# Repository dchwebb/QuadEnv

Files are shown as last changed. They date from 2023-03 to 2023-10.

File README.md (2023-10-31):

# QuadEnv/L4O

Overview
--------
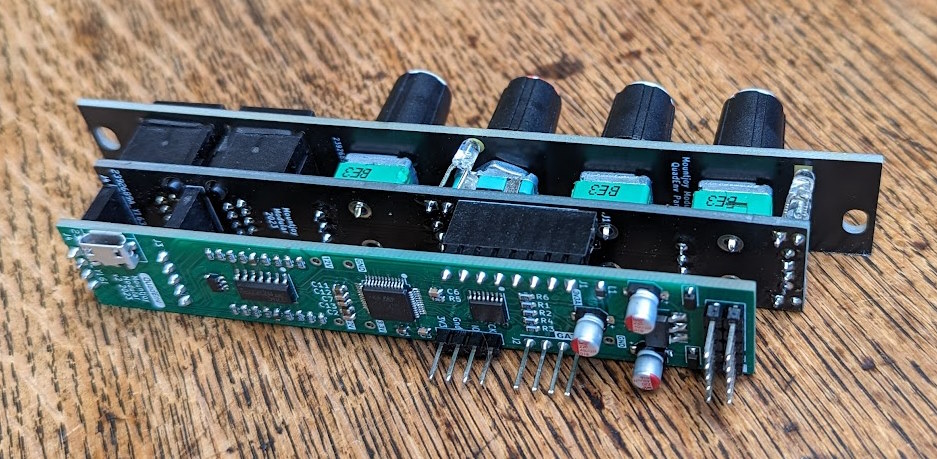
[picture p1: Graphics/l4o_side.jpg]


QuadEnv is a four-voice polyphonic ADSR envelope generator designed for use with the Eurorack Modular Synthesiser architecture. L4O is a four-voice sine wave LFO and uses the same hardware as QuadEnv.

Different front panels are provided for each mode, while the firmware, component and controls boards are dual mode.

As part of a range of compatilble Mountjoy Modular modules, polyphonic interconnections are made using RJ-45 cables (as used for Ethernet).

A USB serial console is provided for customising the envelope times and fade-in rates of the LFOs.

The third potentiometer (Sustain or Fade-In) has a momentary button which allows switching between the envelope and LFO modes via a long press.

QuadEnv
-------
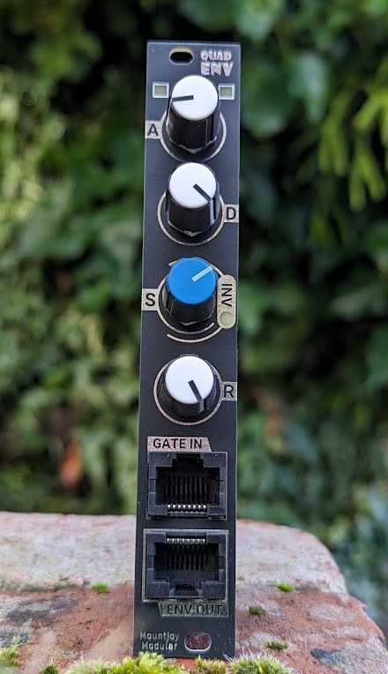
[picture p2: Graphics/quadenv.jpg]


The digital envelopes are modelled on a Roland System 100 system, with logarithmic/exponential attack/decay and release sections. The level of each envelope is displayed in a bank of LEDs at the top of the module.

A short press on the Sustain potentiometer button inverts the envelopes.

The USB serial console allows the envelope times to be scaled up or down for longer or shorter envelopes.

L4O
---
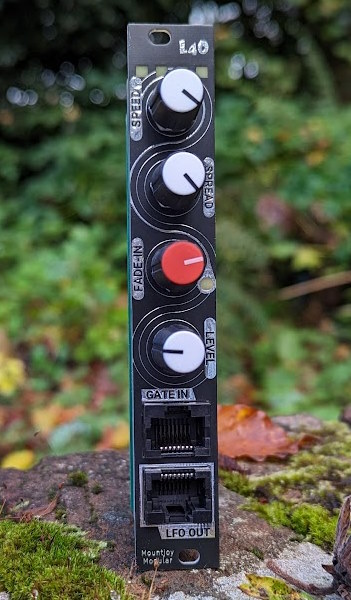
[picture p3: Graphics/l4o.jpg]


The four potentiometers control Speed, Spread, Fade-in and Level. Spread adjusts the variation in LFO speed from one voice to another. Fade-in allows the LFO level to be increased gradually. Short pressing the Fade-in button allows the speed to also be gradually increased. Fade-in starts when a gate is received at the input.

The USB serial interface allows the fade-in times of the level and speed to be independently adjusted.

Technical
---------

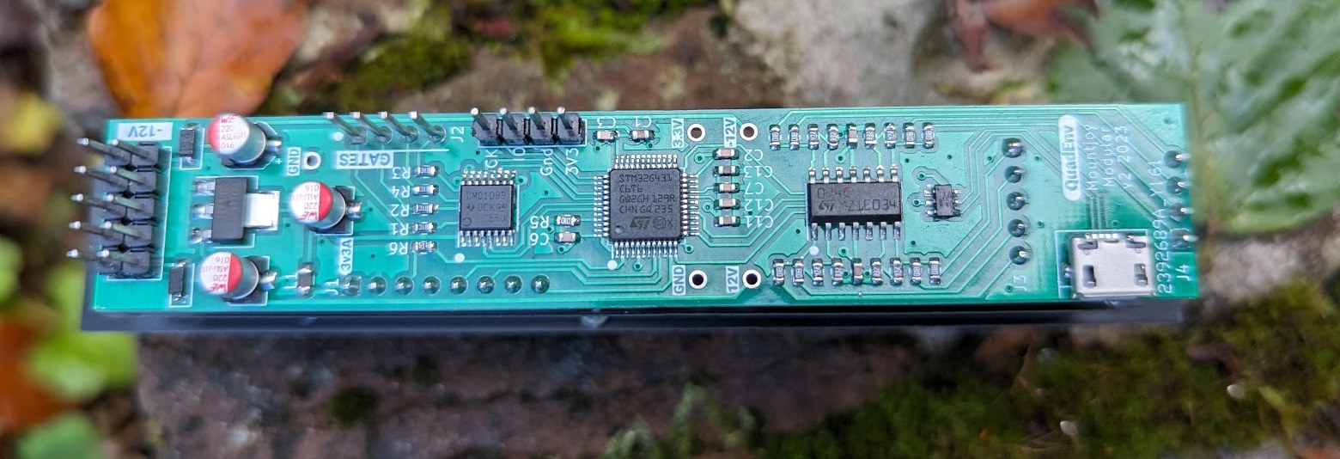
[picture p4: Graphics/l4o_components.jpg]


The module is based around an STM32G431 microcontroller which contains four internal 12 bit DACs used to generate the envelopes at approximately 47kHz.

A CD40109B level shifter provides input protection for the Gate In signals. A TL074 op-amp ampilifies the DAC outputs to around 8 volts at maximum.

Construction is a sandwich of three PCBs with a component board, a controls board and a panel. PCBs designed in Kicad v6.

From version 3 LEDs are controlled by PWM to fix no display when under the LED forward voltage.

[Components schematic v3](https://raw.githubusercontent.com/dchwebb/QuadEnv/master/Component_Schematic_v3.pdf)

[Controls schematic v2](https://raw.githubusercontent.com/dchwebb/QuadEnv/master/Control_Schematic.pdf)

### Power

The Eurorack +/-12V rails have reverse polarity protection and filtering. 3.3V rails are generated with a linear regulator.

- +12V Maximum Current Draw: 80mA

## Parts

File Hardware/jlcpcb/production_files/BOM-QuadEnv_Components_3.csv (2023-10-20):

Comment | Designator | Footprint | LCSC
100nF | C12,C2,C3,C6 | C_0603_1608Metric | C14663
1uF | C10,C11,C13,C9 | C_0603_1608Metric | C15849
4.7uF | C1 | C_0603_1608Metric | C19666
1k | R17,R18,R19,R20,R21,R22,R23,R24 | R_0603_1608Metric | C21190
3k3 | R10,R11,R12,R6,R9 | R_0603_1608Metric | C22978
10k | R1,R13,R14,R15,R16,R2,R3,R4 | R_0603_1608Metric | C23162
100k | R5 | R_0603_1608Metric | C25803
10nF | C7 | C_0603_1608Metric | C57112
LD1117-3.3-4Tab | U2 | SOT-223-3_TabPin2 | C6186
1N5819 | D1,D2 | D_SOD-123 | C8598

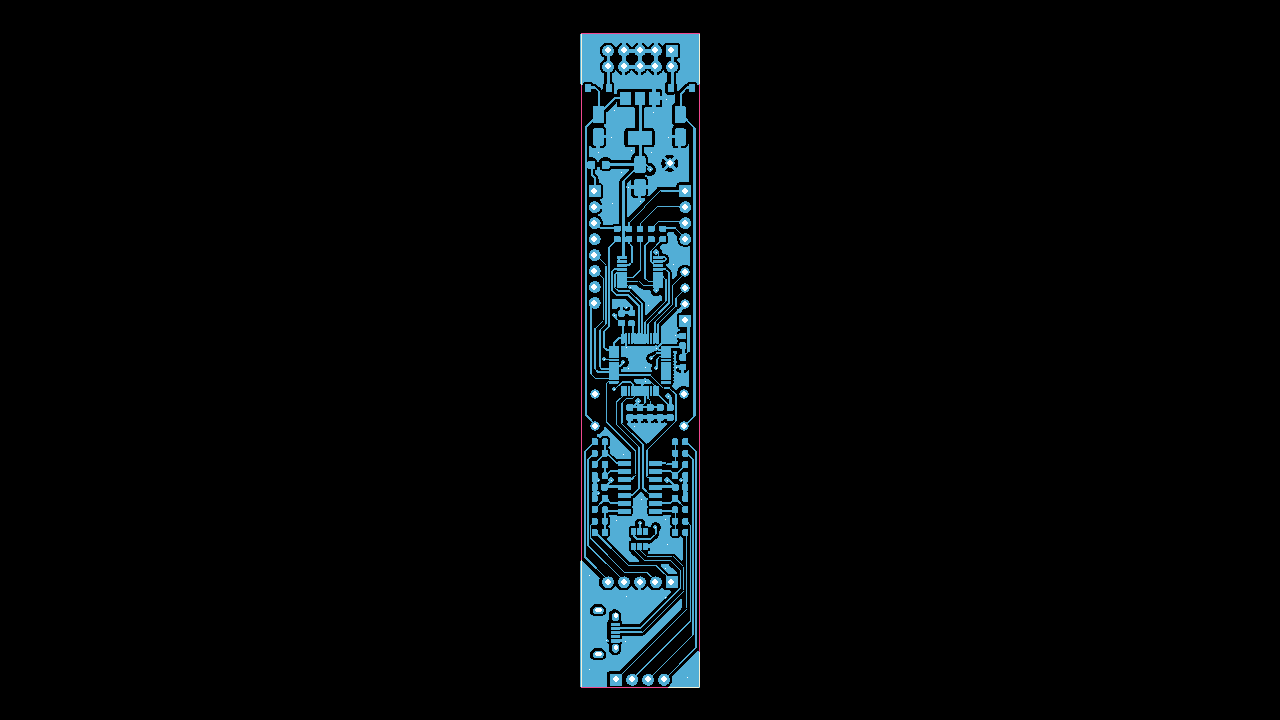
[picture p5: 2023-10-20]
Hardware/Gerbers/2392689A_Y161_QuadEnv_Components_Y161/yg/GBR_5781563_1_snapshot.png

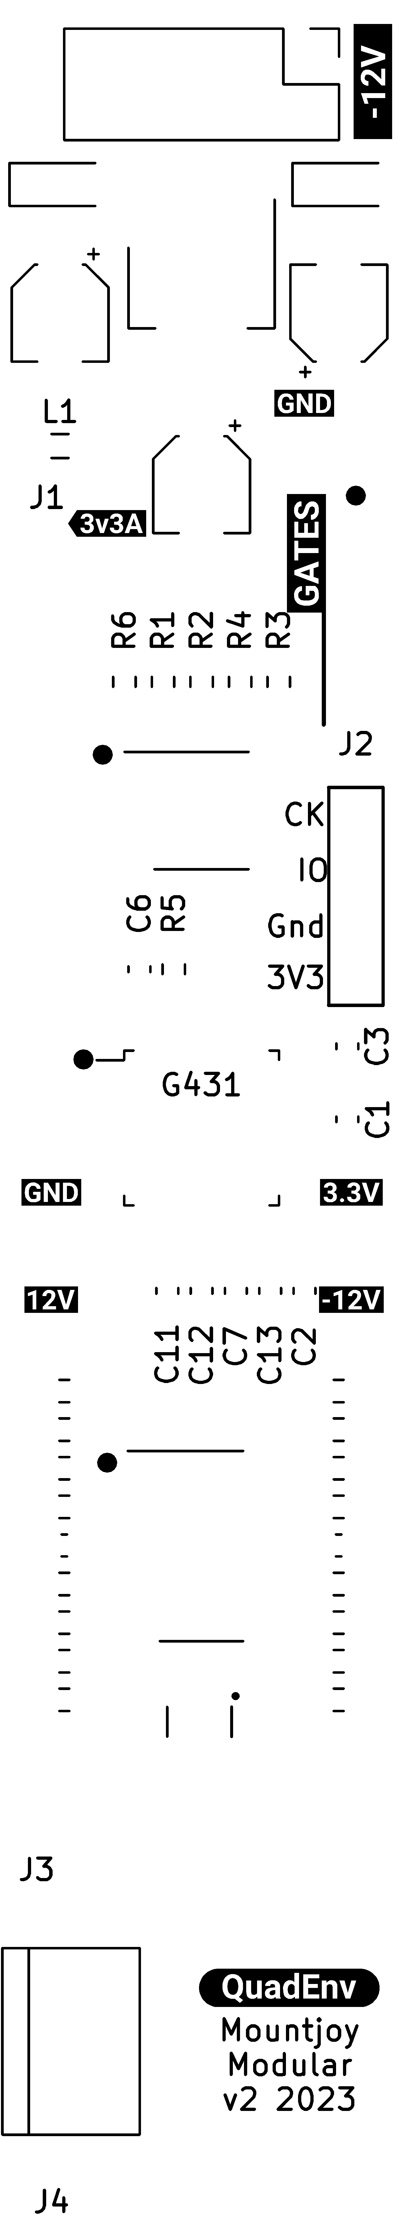
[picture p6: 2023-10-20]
Hardware/Gerbers/2392689A_Y161_QuadEnv_Components_Y161/yg/ul_to.png

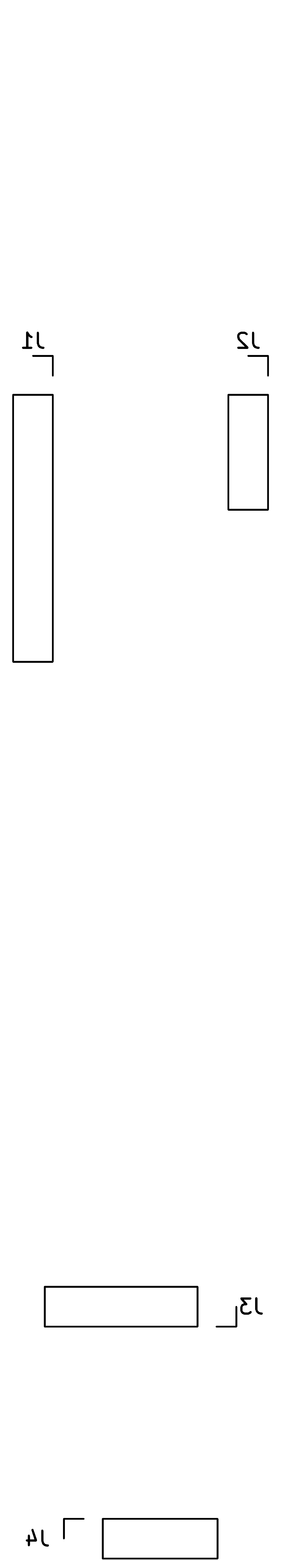
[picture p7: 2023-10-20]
Hardware/Gerbers/2392689A_Y161_QuadEnv_Components_Y161/yg/ul_bo.png

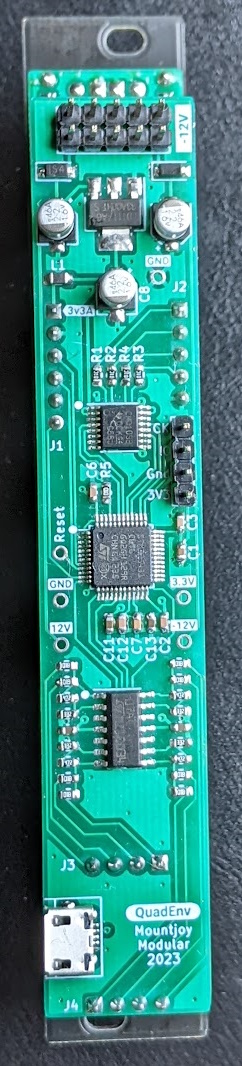
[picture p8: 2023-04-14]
Graphics/quadenv_components.jpg

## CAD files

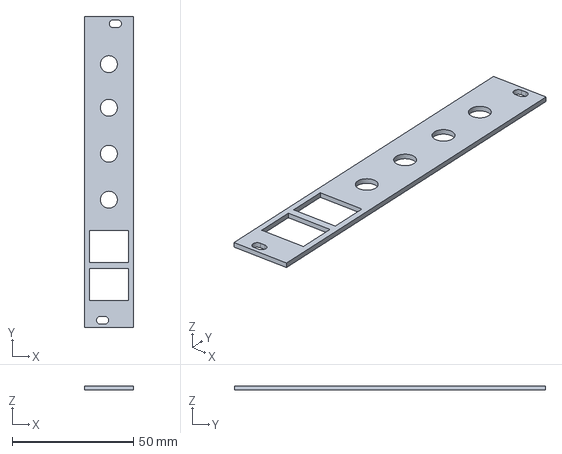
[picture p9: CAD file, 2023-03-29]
Hardware/Graphics/QuadEnv_Panel.step
20.3 x 128.5 x 1.60 mm

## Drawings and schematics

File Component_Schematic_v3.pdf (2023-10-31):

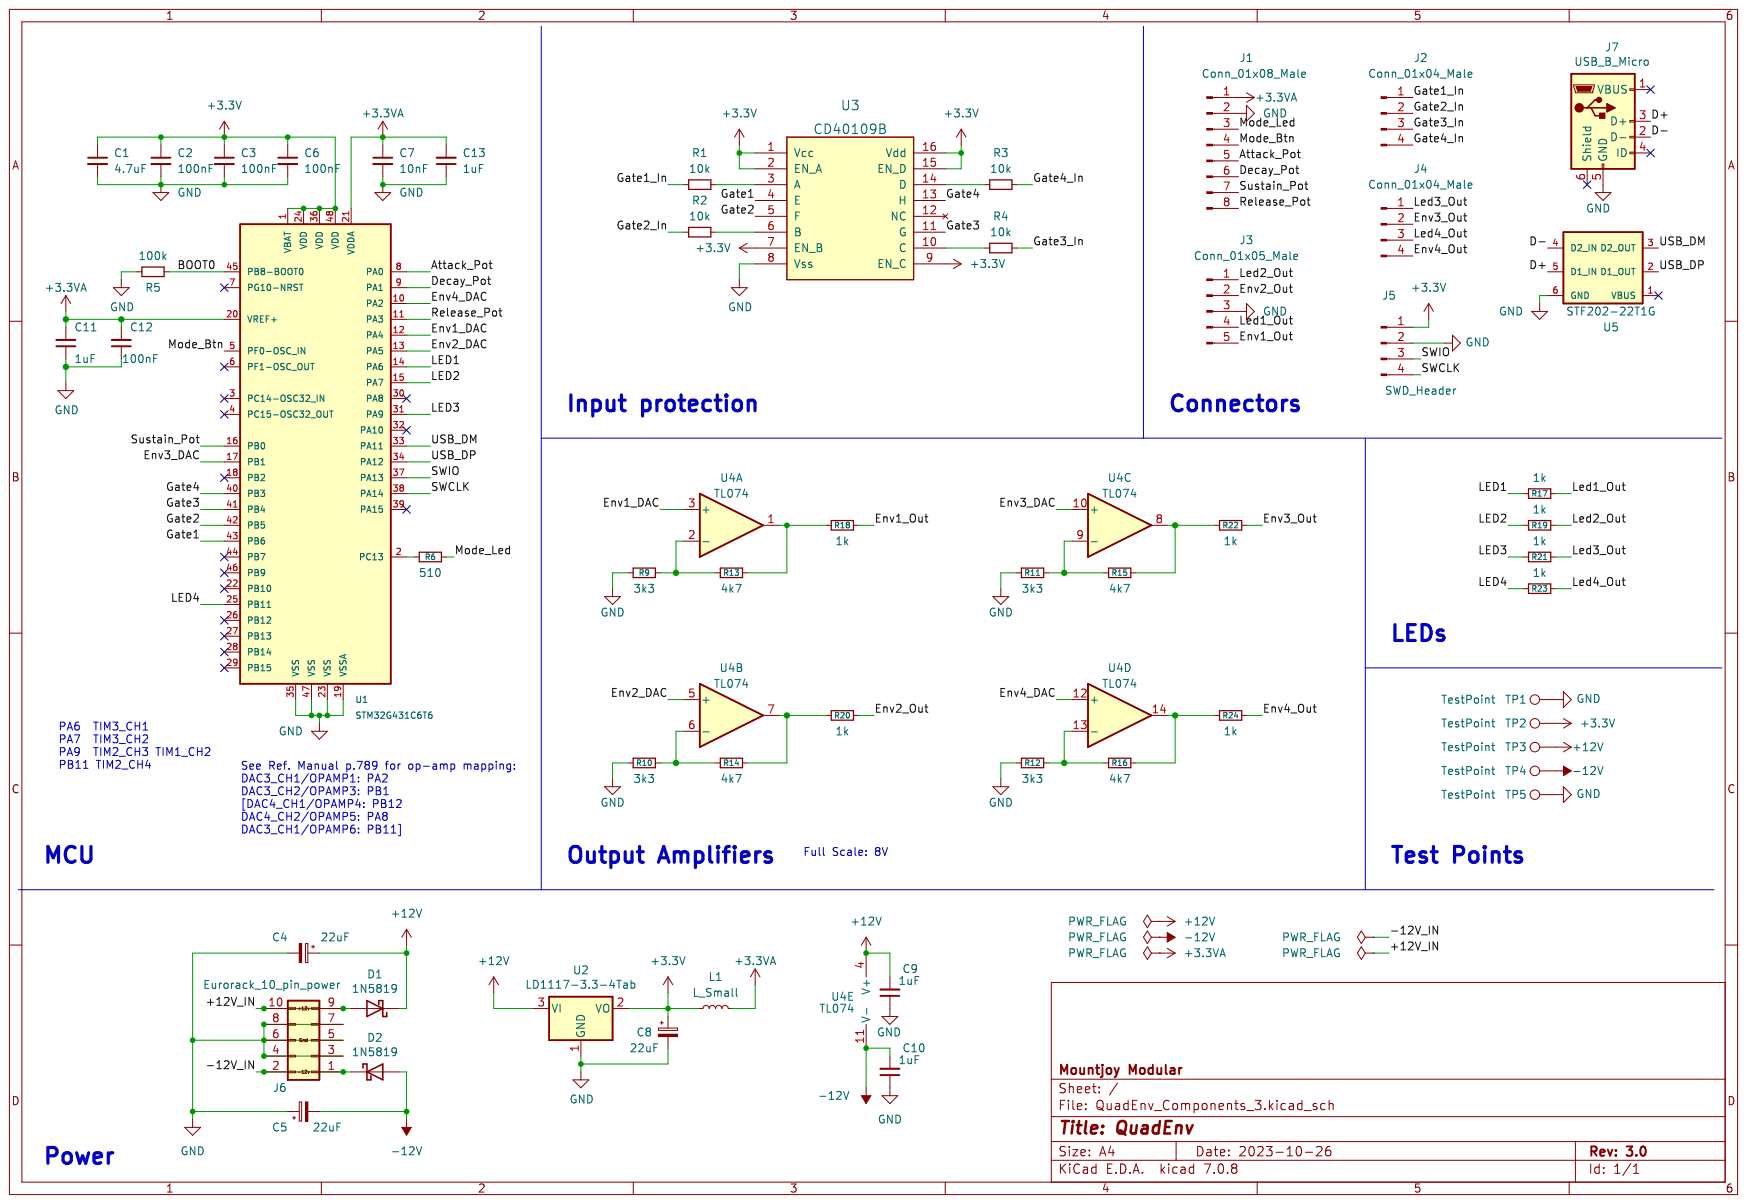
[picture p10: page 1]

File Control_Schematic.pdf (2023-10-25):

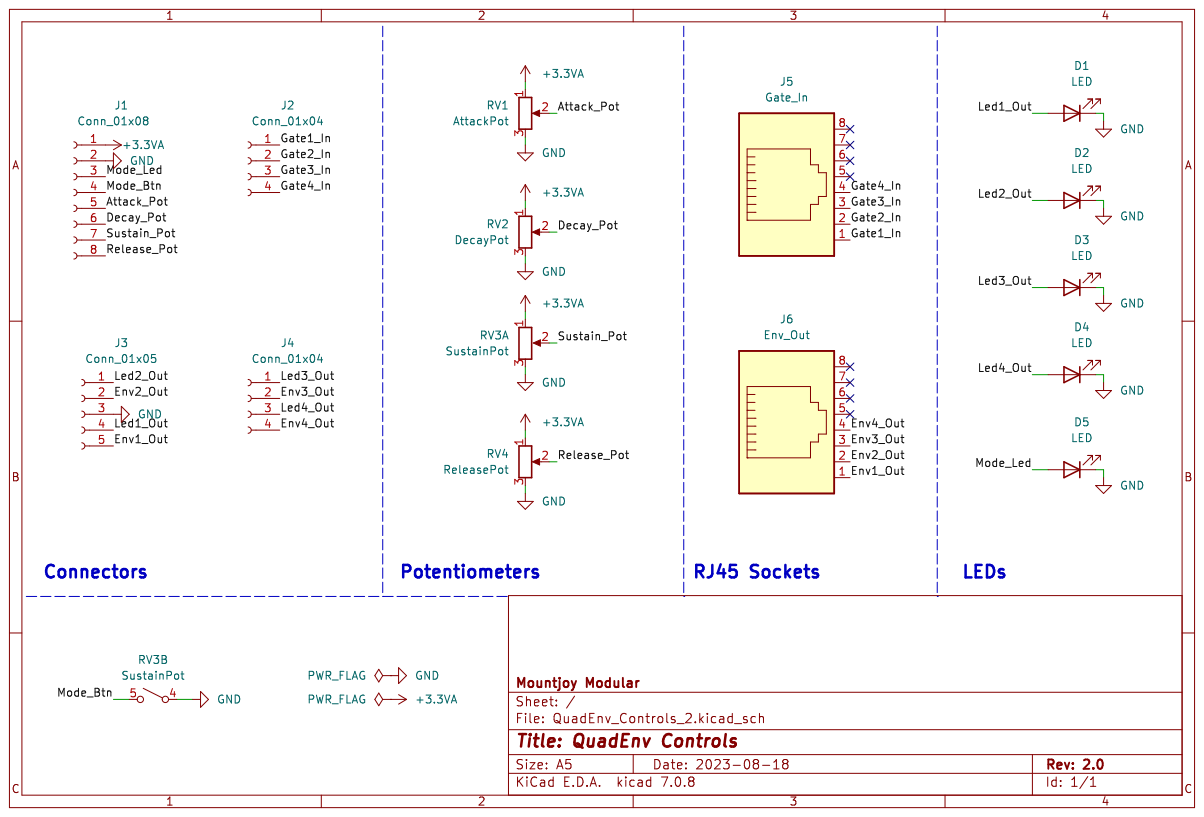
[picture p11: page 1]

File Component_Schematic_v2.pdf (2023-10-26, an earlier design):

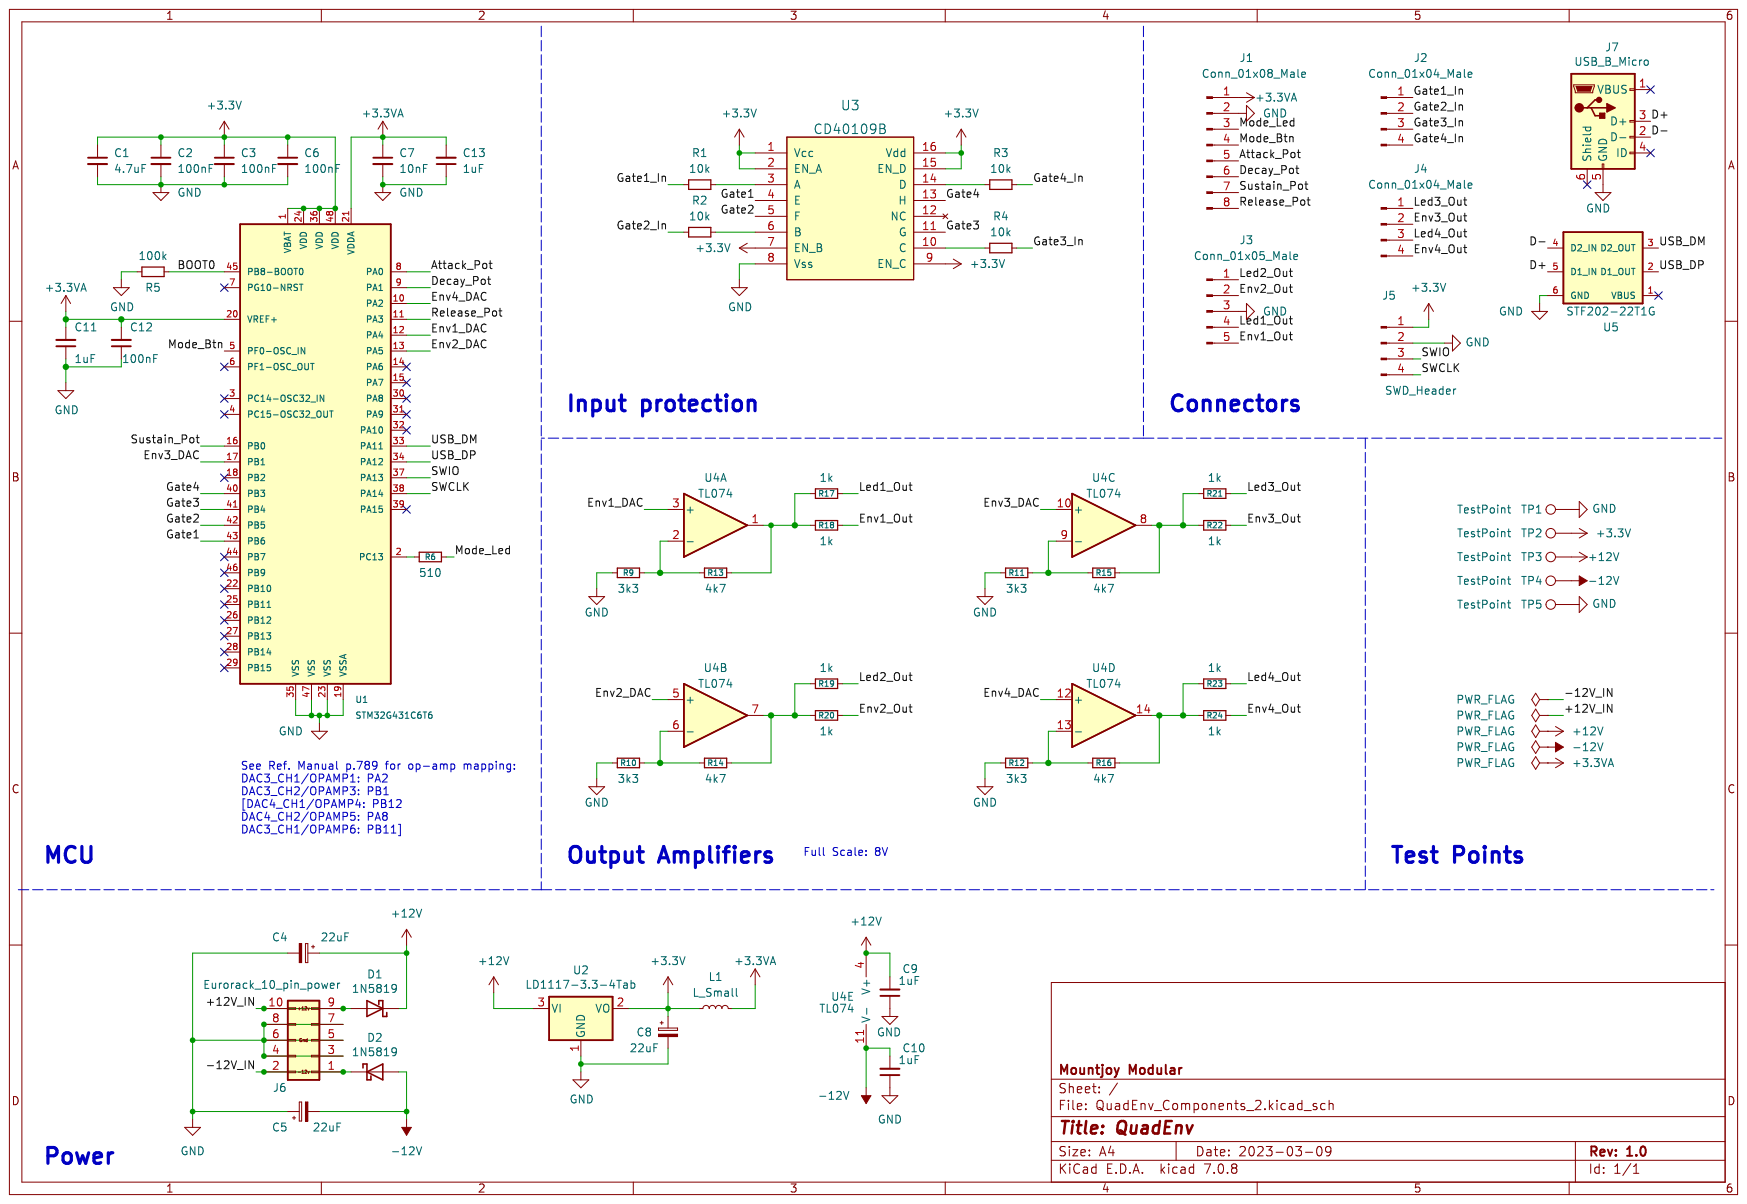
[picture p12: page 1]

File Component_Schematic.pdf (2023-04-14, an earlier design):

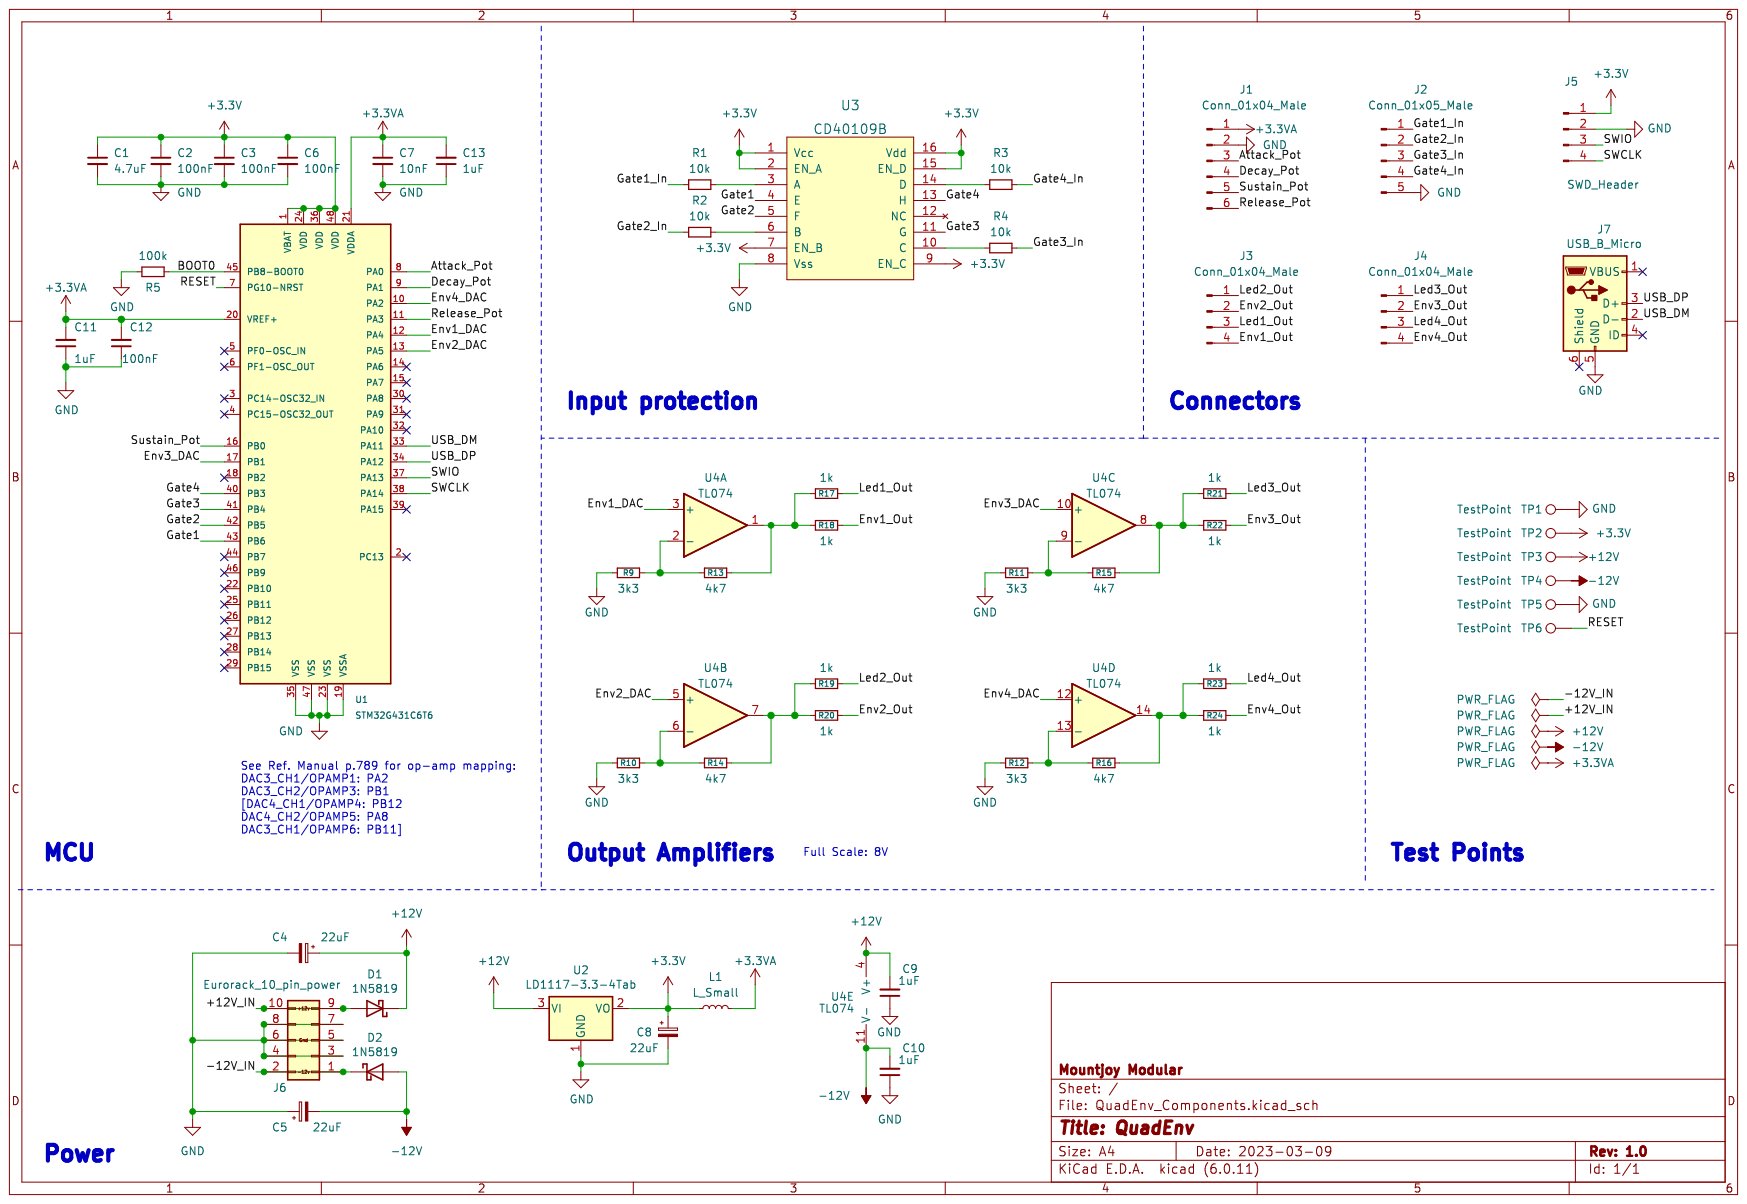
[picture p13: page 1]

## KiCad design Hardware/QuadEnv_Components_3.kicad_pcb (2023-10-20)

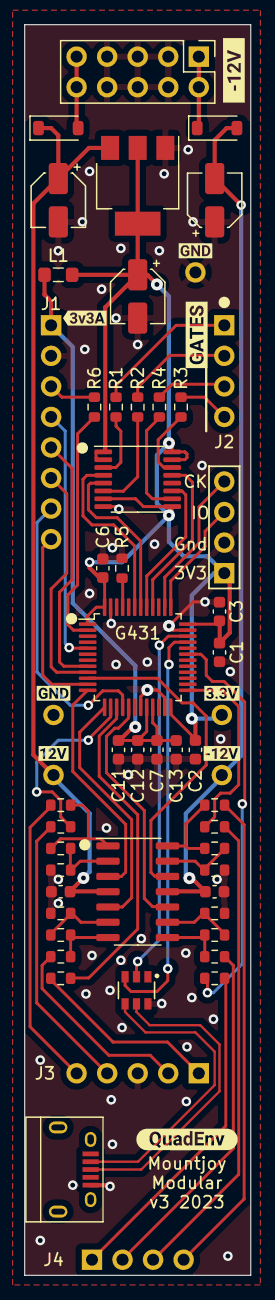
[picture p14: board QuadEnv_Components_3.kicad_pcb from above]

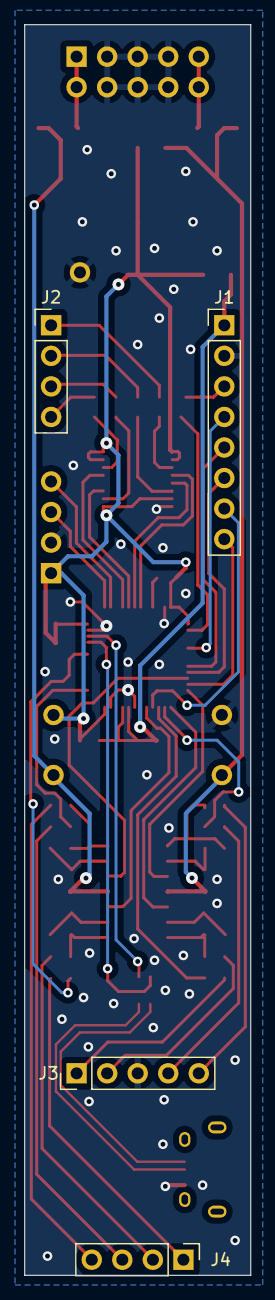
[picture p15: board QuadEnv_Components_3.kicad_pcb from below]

Board: 2 copper layers, 18.8 x 104.0 mm, 64 parts (4 on the bottom side), 57 nets.

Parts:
C1: 4.7uF; C_0603_1608Metric
C2, C3, C6, C12: 100nF; C_0603_1608Metric
C4, C5, C8: 22uF; CP_Elec_4x5.8
C7: 10nF; C_0603_1608Metric
C9, C10, C11, C13: 1uF; C_0603_1608Metric
D1, D2: 1N5819; D_SOD-123
J1: Conn_01x08_Male; PinHeader_1x08_P2.54mm_Vertical
J2, J4: Conn_01x04_Male; PinHeader_1x04_P2.54mm_Vertical
J3: Conn_01x05_Male; PinHeader_1x05_P2.54mm_Vertical
J5: SWD_Header; SWD_header
J6: Eurorack_10_pin_power; PinHeader_2x05_P2.54mm_Vertical
J7: USB_B_Micro; USB_Micro-B_Amphenol
L1: L_Small; L_0805_2012Metric_Pad1.05x1.20mm_HandSolder
R1, R2, R3, R4: 10k; R_0603_1608Metric
R5: 100k; R_0603_1608Metric
R6: 510; R_0603_1608Metric
R9, R10, R11, R12: 3k3; R_0603_1608Metric
R13, R14, R15, R16: 4k7; R_0603_1608Metric
R17, R18, R19, R20, R21, R22, R23, R24: 1k; R_0603_1608Metric
TP1, TP2, TP3, TP4, TP5: TestPoint; 1mm_Test_Point
U1: STM32G431C6T6; LQFP-48_7x7mm_P0.5mm
U2: LD1117-3.3-4Tab; SOT-223-3_TabPin2
U3: CD40109B; TSSOP-16_4.4x5mm_P0.65mm
U4: TL074; SOIC-14_3.9x8.7mm_P1.27mm
U5: STF202-22T1G
kibuzzard-64DF8AE0: G***; kibuzzard-64DF8AE0
kibuzzard-640A0C12: G***; kibuzzard-640A0C12
kibuzzard-6409F893: G***; kibuzzard-6409F893
kibuzzard-6409FE2B: G***; kibuzzard-6409FE2B
kibuzzard-6409FE16: G***; kibuzzard-6409FE16
kibuzzard-6409FE46: G***; kibuzzard-6409FE46
kibuzzard-6409FE57, kibuzzard-6409FE57#2: G***; kibuzzard-6409FE57
kibuzzard-6409FEF9: G***; kibuzzard-6409FEF9

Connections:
+3.3V: C1.1, C2.1, C3.1, C6.1, C8.1, J5.1, L1.1, TP2.1, U1.1 (VBAT), U1.24 (VDD), U1.36 (VDD), U1.48 (VDD), U2.2 (VO), U3.1 (Vcc), U3.2 (EN_A), U3.7 (EN_B), U3.9 (EN_C), U3.15 (EN_D), U3.16 (Vdd)
+3.3VA: C7.1, C11.2, C12.2, C13.2, J1.1, L1.2, U1.20 (VREF+), U1.21 (VDDA)
+12V: C4.1, C9.2, D1.1 (K), TP3.1, U2.3 (VI), U4.4 (V+)
-12V: C5.2, C10.2, D2.2 (A), TP4.1, U4.11 (V-)
/+12V_IN: D1.2 (A), J6.9, J6.10
/-12V_IN: D2.1 (K), J6.1, J6.2
/Attack_Pot: J1.5, U1.8 (PA0)
/BOOT0: R5.2, U1.45 (PB8-BOOT0)
/D+: J7.3 (D+), U5.5 (D1_IN)
/D-: J7.2 (D-), U5.4 (D2_IN)
/Decay_Pot: J1.6, U1.9 (PA1)
/Env1_DAC: U1.12 (PA4), U4.3 (+)
/Env1_Out: J3.5, R18.2
/Env2_DAC: U1.13 (PA5), U4.5 (+)
/Env2_Out: J3.2, R20.2
/Env3_DAC: U1.17 (PB1), U4.10 (+)
/Env3_Out: J4.2, R22.2
/Env4_DAC: U1.10 (PA2), U4.12 (+)
/Env4_Out: J4.4, R24.2
/Gate1: U1.43 (PB6), U3.4 (E)
/Gate1_In: J2.1, R1.1
/Gate2: U1.42 (PB5), U3.5 (F)
/Gate2_In: J2.2, R2.1
/Gate3: U1.41 (PB4), U3.11 (G)
/Gate3_In: J2.3, R4.2
/Gate4: U1.40 (PB3), U3.13 (H)
/Gate4_In: J2.4, R3.2
/LED1: R17.1, U1.14 (PA6)
/LED2: R19.1, U1.15 (PA7)
/LED3: R21.1, U1.31 (PA9)
/LED4: R23.1, U1.25 (PB11)
/Led1_Out: J3.4, R17.2
/Led2_Out: J3.1, R19.2
/Led3_Out: J4.1, R21.2
/Led4_Out: J4.3, R23.2
/Mode_Btn: J1.4, U1.5 (PF0-OSC_IN)
/Mode_Led: J1.3, R6.1
/Release_Pot: J1.8, U1.11 (PA3)
/SWCLK: J5.4, U1.38 (PA14)
/SWIO: J5.3, U1.37 (PA13)
/Sustain_Pot: J1.7, U1.16 (PB0)
/USB_DM: U1.33 (PA11), U5.3 (D2_OUT)
/USB_DP: U1.34 (PA12), U5.2 (D1_OUT)
GND: C1.2, C2.2, C3.2, C4.2, C5.1, C6.2, C7.2, C8.2, C9.1, C10.1, C11.1, C12.1, C13.1, J1.2, J3.3, J5.2, J6.3, J6.4, J6.5, J6.6, J6.7, J6.8, J7.5 (GND), R5.1, R9.2, R10.2, R11.2, R12.2, TP1.1, TP5.1, U1.19 (VSSA), U1.23 (VSS), U1.35 (VSS), U1.47 (VSS), U2.1 (GND), U3.8 (Vss), U5.6 (GND)
unnamed: R13.1, R18.1, U4.1
unnamed: R14.1, R20.1, U4.7
unnamed: R15.1, R22.1, U4.8
unnamed: R16.1, R24.1, U4.14
unnamed: R6.2, U1.2 (PC13)
unnamed: R1.2, U3.3 (A)
unnamed: R2.2, U3.6 (B)
unnamed: R4.1, U3.10 (C)
unnamed: R3.1, U3.14 (D)
unnamed: R9.1, R13.2, U4.2 (-)
unnamed: R10.1, R14.2, U4.6 (-)
unnamed: R11.1, R15.2, U4.9 (-)
unnamed: R12.1, R16.2, U4.13 (-)

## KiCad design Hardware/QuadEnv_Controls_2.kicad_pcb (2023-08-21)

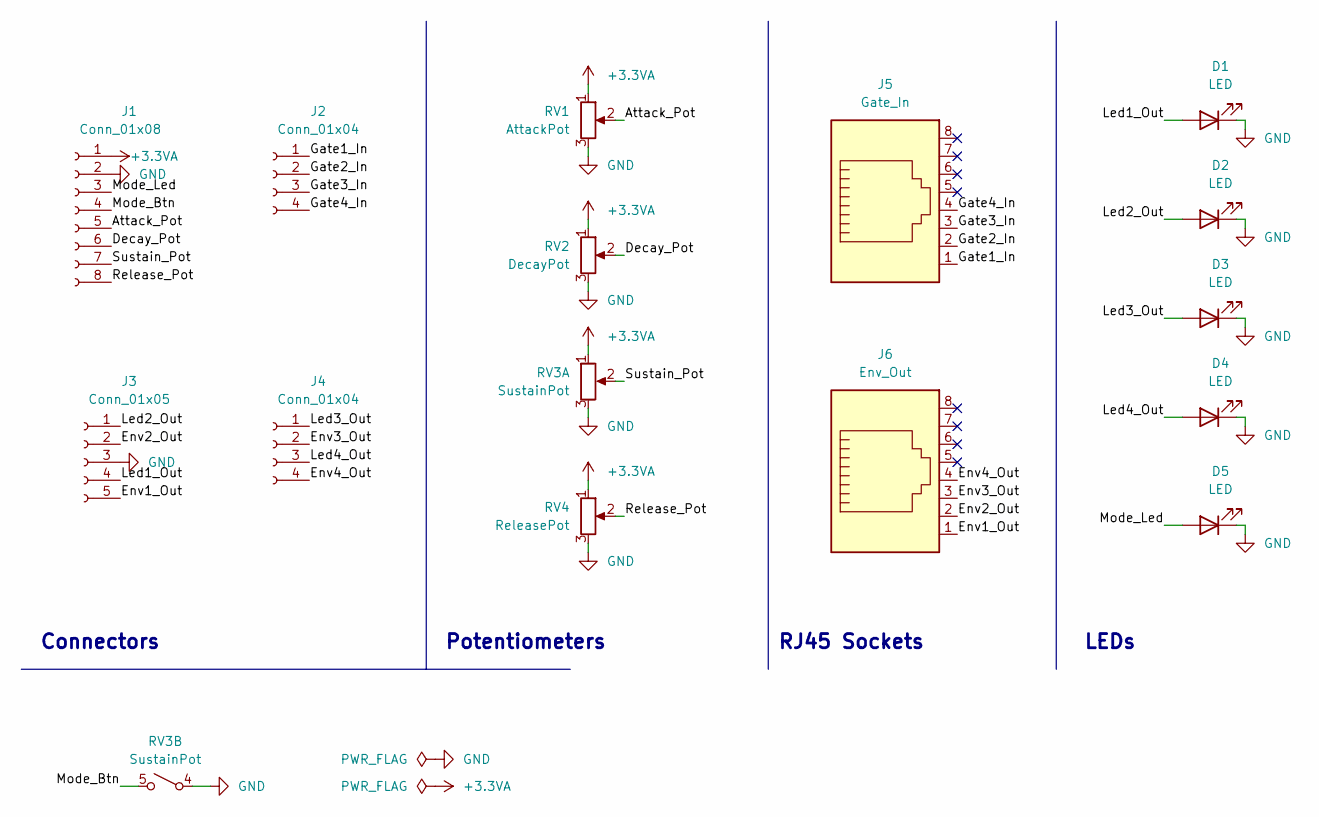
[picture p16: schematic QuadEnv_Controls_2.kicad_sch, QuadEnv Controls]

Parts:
D1, D2, D3, D4, D5: LED; LED_D3.0mm
J1: Conn_01x08; PinSocket_1x08_P2.54mm_Vertical
J2, J4: Conn_01x04; PinSocket_1x04_P2.54mm_Vertical
J3: Conn_01x05; PinSocket_1x05_P2.54mm_Vertical
J5: Gate_In; RJ45_Amphenol_RJHSE-3080
J6: Env_Out; RJ45_Amphenol_RJHSE-3080
RV1: AttackPot; Alpha_9mm_Potentiometer_Aligned
RV2: DecayPot; Alpha_9mm_Potentiometer_Aligned
RV3: SustainPot; Bourns_Switch_Potentiometer
RV4: ReleasePot; Alpha_9mm_Potentiometer_Aligned

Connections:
+3.3VA: J1.1, RV1.1, RV2.1, RV3.1, RV4.1
/Attack_Pot: J1.5, RV1.2
/Decay_Pot: J1.6, RV2.2
/Env1_Out: J3.5, J6.1
/Env2_Out: J3.2, J6.2
/Env3_Out: J4.2, J6.3
/Env4_Out: J4.4, J6.4
/Gate1_In: J2.1, J5.1
/Gate2_In: J2.2, J5.2
/Gate3_In: J2.3, J5.3
/Gate4_In: J2.4, J5.4
/Led1_Out: D1.2 (A), J3.4
/Led2_Out: D2.2 (A), J3.1
/Led3_Out: D3.2 (A), J4.1
/Led4_Out: D4.2 (A), J4.3
/Mode_Btn: J1.4, RV3.5 (2)
/Mode_Led: D5.2 (A), J1.3
/Release_Pot: J1.8, RV4.2
/Sustain_Pot: J1.7, RV3.2
GND: D1.1 (K), D2.1 (K), D3.1 (K), D4.1 (K), D5.1 (K), J1.2, J3.3, RV1.3, RV2.3, RV3.3, RV3.4 (1), RV4.3

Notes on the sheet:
Potentiometers
Connectors
LEDs
RJ45 Sockets

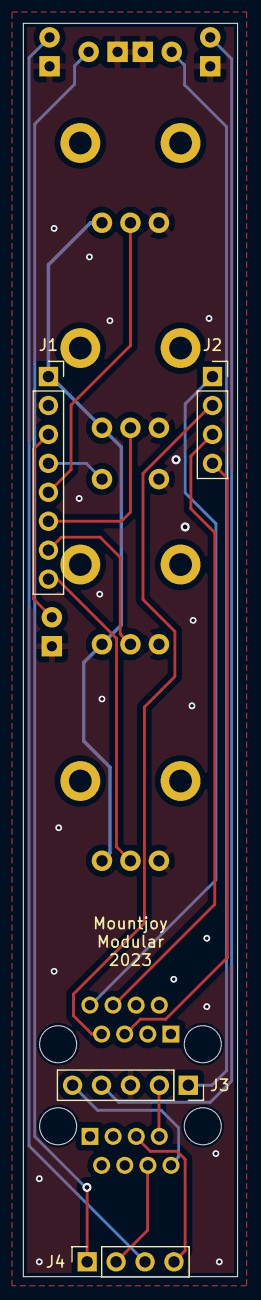
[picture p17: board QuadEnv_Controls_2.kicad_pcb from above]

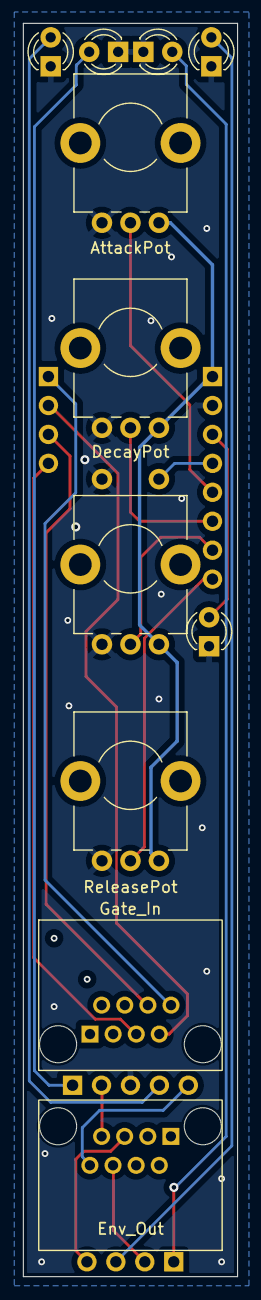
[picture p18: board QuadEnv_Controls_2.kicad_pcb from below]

Board: 2 copper layers, 18.8 x 110.0 mm, 15 parts (11 on the bottom side), 20 nets.

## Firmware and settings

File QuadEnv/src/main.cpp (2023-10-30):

#include "initialisation.h"
#include "envelope.h"
#include "lfo.h"
#include "usb.h"
#include "configManager.h"
#include "Mode.h"

volatile uint32_t SysTickVal;
volatile ADSR adsr;
volatile LFOPots& adc = (volatile LFOPots&)adsr;

extern "C" {
#include "interrupts.h"
}

// Initialise configuration to handle saving and restoring mode, envelope and lfo settings
Config config{&mode.configSaver, &envelopes.configSaver, &lfos.configSaver};

int main(void)
{
	SystemInit();							// Activates floating point coprocessor and resets clock
	InitClocks();							// Configure the clock and PLL
	InitSysTick();
	InitDAC();
	InitIO();
	InitOutputTimer();
	InitPWMTimer();
	InitADC(reinterpret_cast<volatile uint16_t*>(&adsr));
	InitCordic();
	config.RestoreConfig();
	usb.InitUSB();

	while (1) {
		usb.cdc.ProcessCommand();			// Check for incoming CDC commands
	}
}

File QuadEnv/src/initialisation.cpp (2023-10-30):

#include "initialisation.h"

// Settings for HSI at 16MHz
// 16MHz / 4(M) * 85(N) / 2(R) = 170MHz
#define PLL_M 0b011		// 0000 = 1; 0001 = 2; 0010 = 3; 0011 = 4; 0100 = 5; 0101 = 6; 0110 = 7; 0111 = 8; 1000 = 9
#define PLL_N 85
#define PLL_R 0			//  00: PLLR = 2, 01: PLLR = 4, 10: PLLR = 6, 11: PLLR = 8
#define PLL_P 2


void InitClocks(void) {
	// See page 236 for clock configuration
	RCC->APB2ENR |= RCC_APB2ENR_SYSCFGEN;		// SYSCFG + COMP + VREFBUF + OPAMP clock enable
	RCC->APB1ENR1 |= RCC_APB1ENR1_PWREN;		// Enable Power Control clock
	PWR->CR5 &= ~PWR_CR5_R1MODE;				// Select the Range 1 boost mode

	// Configure PLL
	RCC->PLLCFGR = (PLL_M << RCC_PLLCFGR_PLLM_Pos) |
				   (PLL_N << RCC_PLLCFGR_PLLN_Pos) |
				   (PLL_P << RCC_PLLCFGR_PLLPDIV_Pos) |
				   (PLL_R << RCC_PLLCFGR_PLLR_Pos) |
				   RCC_PLLCFGR_PLLSRC_HSI;
	RCC->CR |= RCC_CR_PLLON;					// Enable the main PLL
	RCC->PLLCFGR = RCC_PLLCFGR_PLLREN;			// Enable PLL R (drives AHB clock)
	while ((RCC->CR & RCC_CR_PLLRDY) == 0);		// Wait till the main PLL is ready

	// Configure Flash prefetch and wait state. NB STM32G431 is a category 2 device (128KB flash in 1 bank)
	FLASH->ACR |= FLASH_ACR_LATENCY_4WS | FLASH_ACR_PRFTEN;
	FLASH->ACR &= ~FLASH_ACR_LATENCY_1WS;

	// The system clock must be divided by 2 using the AHB prescaler before switching to a higher system frequency.
	RCC->CFGR |= RCC_CFGR_HPRE_DIV2;			// HCLK = SYSCLK / 2
	RCC->CFGR |= RCC_CFGR_SW_PLL;				// Select the main PLL as system clock source

	// Wait till the main PLL is used as system clock source
	while ((RCC->CFGR & (uint32_t)RCC_CFGR_SWS ) != RCC_CFGR_SWS_PLL);

	// Reset the AHB clock (previously divided by 2) and set APB clocks
	RCC->CFGR &= ~RCC_CFGR_HPRE_Msk;
	RCC->CFGR |= RCC_CFGR_PPRE1_DIV1;			// PCLK1 = HCLK / 1 (APB1)
	RCC->CFGR |= RCC_CFGR_PPRE2_DIV1;			// PCLK2 = HCLK / 1 (APB2)

	SystemCoreClockUpdate();					// Update SystemCoreClock (system clock frequency) derived from settings of oscillators, prescalers and PLL
}


void InitSysTick()
{
	SysTick_Config(SystemCoreClock / SYSTICK);		// gives 1ms
	NVIC_SetPriority(SysTick_IRQn, 0);
}


void InitDAC()
{
	// Configure 4 DAC outputs PA4 and PA5 are regular DAC1 buffered outputs; PA2 and PB1 are DAC3 via OpAmp1 and OpAmp3 (Manual p.789)

	RCC->AHB2ENR |= RCC_AHB2ENR_GPIOAEN;			// Enable GPIO Clock
	RCC->AHB2ENR |= RCC_AHB2ENR_GPIOBEN;			// Enable GPIO Clock
	RCC->AHB2ENR |= RCC_AHB2ENR_DAC1EN;				// Enable DAC Clock
	RCC->AHB2ENR |= RCC_AHB2ENR_DAC3EN;				// Enable DAC Clock

	DAC1->MCR &= ~DAC_MCR_MODE1_Msk;				// Set to normal mode: DAC channel1 is connected to external pin with Buffer enabled
	DAC1->CR |= DAC_CR_EN1;							// Enable DAC using PA4 (DAC_OUT1)

	DAC1->MCR &= ~DAC_MCR_MODE2_Msk;				// Set to normal mode: DAC channel2 is connected to external pin with Buffer enabled
	DAC1->CR |= DAC_CR_EN2;							// Enable DAC using PA5 (DAC_OUT2)

	// output triggered with DAC->DHR12R1 = x;

	// Opamp for DAC3 Channel 1: Follower configuration mode - output on PA2
	DAC3->MCR |= DAC_MCR_MODE1_0 | DAC_MCR_MODE1_1;	// 011: DAC channel1 is connected to on chip peripherals with Buffer disabled
	DAC3->CR |= DAC_CR_EN1;							// Enable DAC

	OPAMP1->CSR |= OPAMP_CSR_VMSEL;					// 11: Opamp_out connected to OPAMPx_VINM input
	OPAMP1->CSR |= OPAMP_CSR_VPSEL;					// 11: DAC3_CH1  connected to OPAMP1 VINP input
	OPAMP1->CSR |= OPAMP_CSR_OPAMPxEN;				// Enable OpAmp: voltage on pin OPAMPx_VINP is buffered to pin OPAMPx_VOUT (PA2)

	// Opamp for DAC3 Channel 2: Follower configuration mode - output on PB1
	// NB According to manual p.790 this should only work on category 3/4 devices and STM32G431 is category 2, but tested working
	DAC3->MCR |= DAC_MCR_MODE2_0 | DAC_MCR_MODE2_1;	// 011: DAC channel2 is connected to on chip peripherals with Buffer disabled
	DAC3->CR |= DAC_CR_EN2;							// Enable DAC

	OPAMP3->CSR |= OPAMP_CSR_VMSEL;					// 11: Opamp_out connected to OPAMPx_VINM input
	OPAMP3->CSR |= OPAMP_CSR_VPSEL;					// 11: DAC3_CH2  connected to OPAMP1 VINP input
	OPAMP3->CSR |= OPAMP_CSR_OPAMPxEN;				// Enable OpAmp: voltage on pin OPAMPx_VINP is buffered to pin OPAMPx_VOUT (PB1)
}


void InitIO()
{
	// MODER 00: Input mode, 01: General purpose output mode, 10: Alternate function mode, 11: Analog mode (reset state)

	RCC->AHB2ENR |= RCC_AHB2ENR_GPIOAEN;			// reset and clock control - advanced high performance bus - GPIO port A
	RCC->AHB2ENR |= RCC_AHB2ENR_GPIOBEN;			// reset and clock control - advanced high performance bus - GPIO port B
	RCC->AHB2ENR |= RCC_AHB2ENR_GPIOCEN;			// Reset and clock control - GPIO port C
	RCC->AHB2ENR |= RCC_AHB2ENR_GPIOFEN;			// Reset and clock control - GPIO port F

	// NB PB6 is used in USB Power delivery and by default has a pull down to ground - disable in the PWR register (datasheet p.60 note 5)
	PWR->CR3 |= PWR_CR3_UCPD_DBDIS;

	GPIOB->MODER &= ~GPIO_MODER_MODER6;				// configure PB6 gate 1 input
	GPIOB->MODER &= ~GPIO_MODER_MODER5;				// configure PB5 gate 2 input
	GPIOB->MODER &= ~GPIO_MODER_MODER4;				// configure PB4 gate 3 input
	GPIOB->MODER &= ~GPIO_MODER_MODER3;				// configure PB3 gate 4 input

	GPIOF->MODER &= ~GPIO_MODER_MODER0;				// PF0 Fade-in Button input
	GPIOF->PUPDR |= GPIO_PUPDR_PUPD0_0;				// 00: None; *01: Pull-up; 10: Pull-down

	GPIOC->MODER &= ~GPIO_MODER_MODE13_1;			// PC13 LED Out
}


void InitOutputTimer()
{
	//	Setup Timer on an interrupt to trigger sample output

	RCC->APB1ENR1 |= RCC_APB1ENR1_TIM4EN;			// Enable Timer
	TIM4->PSC = 34;									// Set prescaler
	TIM4->ARR = 103; 								// Set auto reload register - 170Mhz / 33 / 103 = ~50kHz

	TIM4->DIER |= TIM_DIER_UIE;						// DMA/interrupt enable register
	NVIC_EnableIRQ(TIM4_IRQn);
	NVIC_SetPriority(TIM4_IRQn, 0);					// Lower is higher priority

	TIM4->CR1 |= TIM_CR1_CEN;
	TIM4->EGR |= TIM_EGR_UG;						//  Re-initializes counter and generates update of registers
}


void InitAdcPins(ADC_TypeDef* ADC_No, std::initializer_list<uint8_t> channels)
{
	uint8_t sequence = 1;

	for (auto channel: channels) {
		// Set conversion sequence to order ADC channels are passed to this function
		if (sequence < 5) {
			ADC_No->SQR1 |= channel << ((sequence) * 6);
		} else if (sequence < 10) {
			ADC_No->SQR2 |= channel << ((sequence - 5) * 6);
		} else if (sequence < 15) {
			ADC_No->SQR3 |= channel << ((sequence - 10) * 6);
		} else {
			ADC_No->SQR4 |= channel << ((sequence - 15) * 6);
		}

		// 000: 3 cycles, 001: 15 cycles, 010: 28 cycles, 011: 56 cycles, 100: 84 cycles, 101: 112 cycles, 110: 144 cycles, 111: 480 cycles
		if (channel < 10) {
			ADC_No->SMPR1 |= 0b010 << (3 * channel);
		} else {
			ADC_No->SMPR2 |= 0b010 << (3 * (channel - 10));
		}
		sequence++;
	}
}
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

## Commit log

2023-03-04 ADC with DMA configured
2023-03-04 Created PWM Timer initialisation
2023-03-05 Created PWM interrupt; started converting envelope code
2023-03-05 Started roughing out component PCB layout
    [QuadEnv_Components.kicad_pcb, QuadEnv_Components.kicad_sch]
2023-03-06 Started adding UART
    Though tests show that UART1 is not connected by default on Nucleo
    [QuadEnv_Components.kicad_pcb, QuadEnv_Components.kicad_sch]
2023-03-06 UART2 tested working on Nucleo
2023-03-09 Completed first draft of components PCB
    [QuadEnv_Components-B_Cu.gbr, QuadEnv_Components-B_Mask.gbr, QuadEnv_Components-B_Paste.gbr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]
2023-03-10 First draft of control PCB complete
    [QuadEnv_Components.kicad_pcb, QuadEnv_Components.kicad_sch, QuadEnv_Controls.kicad_pcb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]
2023-03-10 First draft of Panel complete
    [QuadEnv_Components.kicad_pcb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]
2023-03-11 Started creating firmware for STM32G431
    [QuadEnv_Panel.kicad_pcb]
2023-03-12 Added PWM Test code
    [QuadEnv_Components-B_Cu.gbr, QuadEnv_Components-B_Mask.gbr, QuadEnv_Components-B_Silkscreen.gbr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]
2023-03-29 Clean up project for manufacture
    Fixed LED ordering bug on control board
    [QuadEnv_Components-B_Cu.gbr, QuadEnv_Components-B_Mask.gbr, QuadEnv_Components-B_Paste.gbr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]
2023-04-11 Corrections to schematic to fix sustain and release pots being switched
    +Updated project to use production module parts and connections
    [QuadEnv_Components-B_Cu.gbr, QuadEnv_Components-B_Mask.gbr, QuadEnv_Components-B_Paste.gbr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]
2023-04-11 Started tweaking envelope parameters from ADC
2023-04-13 Remove old project files relating to STM32C031
    [QuadEnv_Components.kicad_pcb, QuadEnv_Components.kicad_sch]
2023-04-14 Started adding readme;
    Clean CubeIDE project created to fix issues in current project
    [QuadEnv_Controls.kicad_sch]
2023-07-13 Cleaned up project structure
    [QuadEnv_Components-B_Cu.gbr, QuadEnv_Components-B_Mask.gbr, QuadEnv_Components-B_Paste.gbr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]
2023-08-18 Updated components and controls to include mode button/led
    [QuadEnv_Components_2.kicad_pcb, QuadEnv_Components_2.kicad_sch, QuadEnv_Controls.kicad_pcb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]
2023-08-20 Updated to version 2 of panel
    [QuadEnv_Components_2.kicad_pcb, QuadEnv_Controls_2.kicad_pcb, QuadEnv_Controls_2.kicad_sch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]
2023-08-21 Completed v2 design
    [QuadEnv_Controls_2.kicad_pcb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]
2023-08-21 Generated gerbers for v2 production
    [QuadEnv_Components-B_Cu.gbr, QuadEnv_Components-B_Mask.gbr, QuadEnv_Components-B_Paste.gbr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]
2023-08-21 Updated Gerbers and Ordered
    [QuadEnv_Components_2-B_Cu.gbr, QuadEnv_Components_2-B_Mask.gbr, QuadEnv_Components_2-B_Silkscreen.gbr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]
2023-10-20 New component board with PWM LEDs; started refactor for invert button
    [BOM-QuadEnv_Components_3.csv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]
2023-10-20 Implemented envelope inverting logic
    [initialisation.cpp]
2023-10-25 Started to merge with L4O code
    [QuadEnv_Components_3.kicad_sch]
2023-10-25 Long press on mode button will switch between envelope and lfo mode
2023-10-25 Moved L4O panel files into project; Updated Controls schematic to v2
    [L4O_Panel-B_Cu.gbr, L4O_Panel-B_Mask.gbr, L4O_Panel-B_Silkscreen.gbr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]
2023-10-26 Updated component schematic
    [QuadEnv_Components_2.kicad_sch]
2023-10-30 Updated firmware to output levels on PWM LEDs for v3 hardware
    [QuadEnv_Components_2.kicad_sch, QuadEnv_Components_3.kicad_sch]
2023-10-31 Updated schematic
    [QuadEnv_Components_3.kicad_sch]
